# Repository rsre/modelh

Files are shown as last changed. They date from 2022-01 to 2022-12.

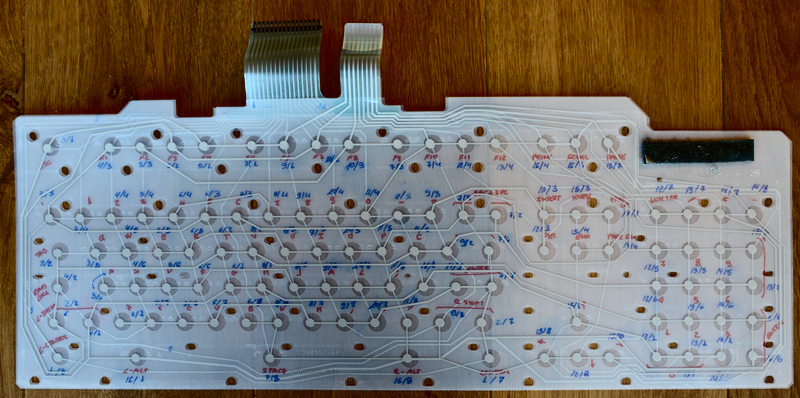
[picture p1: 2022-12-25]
firm/matrix/DSC_9299.jpg

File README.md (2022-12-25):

# Model H
Replacement Model M controller board



Still a work in progress.

## Part list

### 16 + 8 + 4 Pin Ribbons
* CONN FFC VERT 16POS 2.54MM PCB - https://www.digikey.com/products/en?keywords=A144434-ND
* CONN FFC VERT 8POS 2.54MM PCB - https://www.digikey.com/products/en?keywords=5-520315-8-ND
* CONN FFC VERT 4POS 2.54MM PCB - https://www.digikey.com/products/en?keywords=A123169-ND

### 16 + 12 Pin Ribbons
* CONN FFC VERT 16POS 2.54MM PCB - https://www.digikey.com/products/en?keywords=A144434-ND
* CONN FFC VERT 12POS 2.54MM PCB - https://www.digikey.com/products/en?keywords=A123179-ND

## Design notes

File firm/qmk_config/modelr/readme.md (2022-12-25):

# modelr

modelr

*A short description of the keyboard/project*

* Keyboard Maintainer: [Ricardo](https://github.com/rsre)
* Hardware Supported: *The PCBs, controllers supported*
* Hardware Availability: *Links to where you can find this hardware*

Make example for this keyboard (after setting up your build environment):

    make modelr:default

Flashing example for this keyboard:

    make modelr:default:flash

See the [build environment setup](https://docs.qmk.fm/#/getting_started_build_tools) and the [make instructions](https://docs.qmk.fm/#/getting_started_make_guide) for more information. Brand new to QMK? Start with our [Complete Newbs Guide](https://docs.qmk.fm/#/newbs).

## Bootloader

Enter the bootloader in 3 ways:

* **Bootmagic reset**: Hold down the key at (0,0) in the matrix (usually the top left key or Escape) and plug in the keyboard
* **Physical reset button**: Briefly press the button on the back of the PCB - some may have pads you must short instead
* **Keycode in layout**: Press the key mapped to `RESET` if it is available

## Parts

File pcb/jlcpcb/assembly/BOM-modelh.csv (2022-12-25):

Comment | Designator | Footprint | LCSC
1M | R11 | R_0603_1608Metric | C26098
8MHz | Y1 | Crystal_SMD_5032-2Pin_5.0x3.2mm | C115962
100nF | C10,C11,C12,C13,C14,C2,C4,C9 | C_0402_1005Metric | C1525
20pF | C5,C6 | C_0603_1608Metric | C1653
TYPE-C-31-M-12 | USB_C1 | USB_C_Receptacle_HRO_TYPE-C-31-M-12 | C165948
100 | R7,R8,R9 | R_0805_2012Metric | C17408
0 | R12,R13,R14,R15 | R_0805_2012Metric_Pad1.15x1.40mm_HandSolder | C17477
10uF | C1,C3 | C_0603_1608Metric | C19702
1.5k | R10,R16,R5 | R_0603_1608Metric | C22843
1M | R6 | R_0603_1608Metric | C22935
green | LED1,LED2 | LED_0805_2012Metric | C2297
330 | R1,R2 | R_0603_1608Metric | C23138
22 | R3,R4 | R_0603_1608Metric | C23345
100k | R17,R18 | R_0603_1608Metric | C25803
SW_Push | SW1 | SW_SPST_EVPBF | C318888
AMS1117-3.3 | U2 | SOT-223-3_TabPin2 | C6186
GD32F103C8T6 | U1 | LQFP-48_7x7mm_P0.5mm | C77994
Conn_02x05_Odd_Even | Debug1 | IDC-Header_2x05_P2.54mm_Vertical
Conn_02x03_Odd_Even | boot_selector1 | PinHeader_2x03_P2.54mm_Vertical
Conn_01x05 | custom_leds_C1 | PinSocket_1x05_P2.54mm_Vertical
Conn_01x05 | custom_leds_B1 | PinSocket_1x05_P2.54mm_Vertical
Conn_01x05 | custom_leds_A1 | PinSocket_1x05_P2.54mm_Vertical
TestPoint | TP1 | TestPoint_THTPad_D1.5mm_Drill0.7mm
5-520315-4 | LEDs1 | CONN_5-520315-4_TYC
6-520315-2 | Rows1 | CONN_6-520315-2_TYC
6-520315-6 | Columns1 | CONN_6-520315-6_TYC

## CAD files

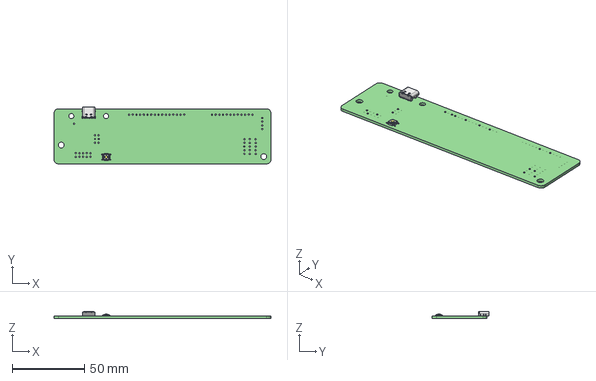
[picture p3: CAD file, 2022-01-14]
pcb/modelh.step
150.0 x 39.2 x 4.81 mm
modelh PCB

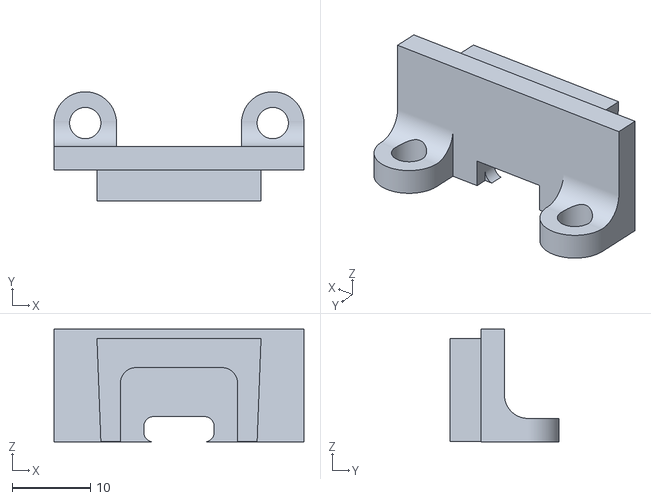
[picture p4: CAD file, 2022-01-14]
shim/shim.stl
32.0 x 14.0 x 14.4

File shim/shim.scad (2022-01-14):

$fn = 128;

total_height = 13.2;
ridge_height = 1.2;
pcb_height = 1.6;

usb_b_port_width = 12.5;
usb_b_port_height = 11.6;

module usb_b_port() {
	translate([-(usb_b_port_width / 2), -5,0])
		cube([usb_b_port_width, 18, usb_b_port_height]);
}

usb_c_port_width = 9;
usb_c_port_height = 3.25;
usb_c_port_radius = 1.25;
module usb_c_port() {
    r = usb_c_port_radius;
    w = usb_c_port_width;
    h = usb_c_port_height;
    
    translate([0,10,pcb_height])hull(){
        translate([-(w/2)+r, 0, -(h/2)+r])
            rotate([90,0,0])cylinder(h=18, r=r);
        translate([(w/2)-r, 0, -(h/2)+r])
            rotate([90,0,0])cylinder(h=18, r=r);
        translate([-(w/2)+r, 0, (h/2)-r])
            rotate([90,0,0])cylinder(h=18, r=r);
        translate([(w/2)-usb_c_port_radius, 0, (h/2)-r])
            rotate([90,0,0])cylinder(h=18, r=r);
    }
    
    translate([-(usb_c_port_width / 2), 1.5,0])
		cube([usb_c_port_width, 10, usb_c_port_height]);
    
    
    indentation_width = 15;
    indentation_height = 7.5;
    indentation_depth = 3.81;
    indentation_radius = 2;
    
    translate([-indentation_width/2, -4.01, 0])hull(){
        translate([indentation_width-indentation_radius, indentation_depth, indentation_height])
            rotate([90,0,0])cylinder(h=indentation_depth, r=indentation_radius);
        translate([+indentation_radius, indentation_depth, indentation_height])
            rotate([90,0,0])cylinder(h=indentation_depth, r=indentation_radius);
		cube([indentation_width, indentation_depth, indentation_height-indentation_radius]);
    }
}

module pegs() {
	translate([-12,6,0])
		cylinder(10, 2, 2);
	translate([12,6,0])
		cylinder(10, 2, 2);
}

module outer() {
    port_height = total_height;
    port_width_small = 20;
    port_width_big = 21;
    port_thickness = 4;
	
    translate([0, 0, 0.01])
        difference(){
            linear_extrude(height = port_height, scale = port_width_big/port_width_small) square(port_width_small, center = true);
            translate([-25/2,-20-port_thickness,-1])cube([25, 20, port_height+2]);
            translate([-25/2,3,-1])cube([25, 20, port_height+2]);
        }
}

module inner() {
	translate([-16, 0, 0.01])
		cube([32, 3, total_height + ridge_height]);
}

module base() {
	difference() {
		union() {
			translate([-16, 0, 0.01])
				cube([32, 6, 3]);
			translate([-12,6,0.01])
				cylinder(3, 4, 4);
			translate([12,6,0.01])
				cylinder(3, 4, 4);

			translate([-16, 0, 3])
				cube([32, 6, 3]);
		}
		union() {
			translate([-8,-5,0])
				cube([16, 18, 11]);

			translate([-16.1,6,6]) {
				rotate([0,90,0]) {
					cylinder(33, 3, 3);
				}
			}
		}
	}
}


module fill() {
	outer();
	inner();
	base();
}

//translate([88.78,-46,-pcb_height])rotate([0,0,180])color("blue")import("../pcb/modelh.stl");

difference() {
	fill();
	usb_c_port();
	pegs();
}

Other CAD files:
pcb/modelh.stl

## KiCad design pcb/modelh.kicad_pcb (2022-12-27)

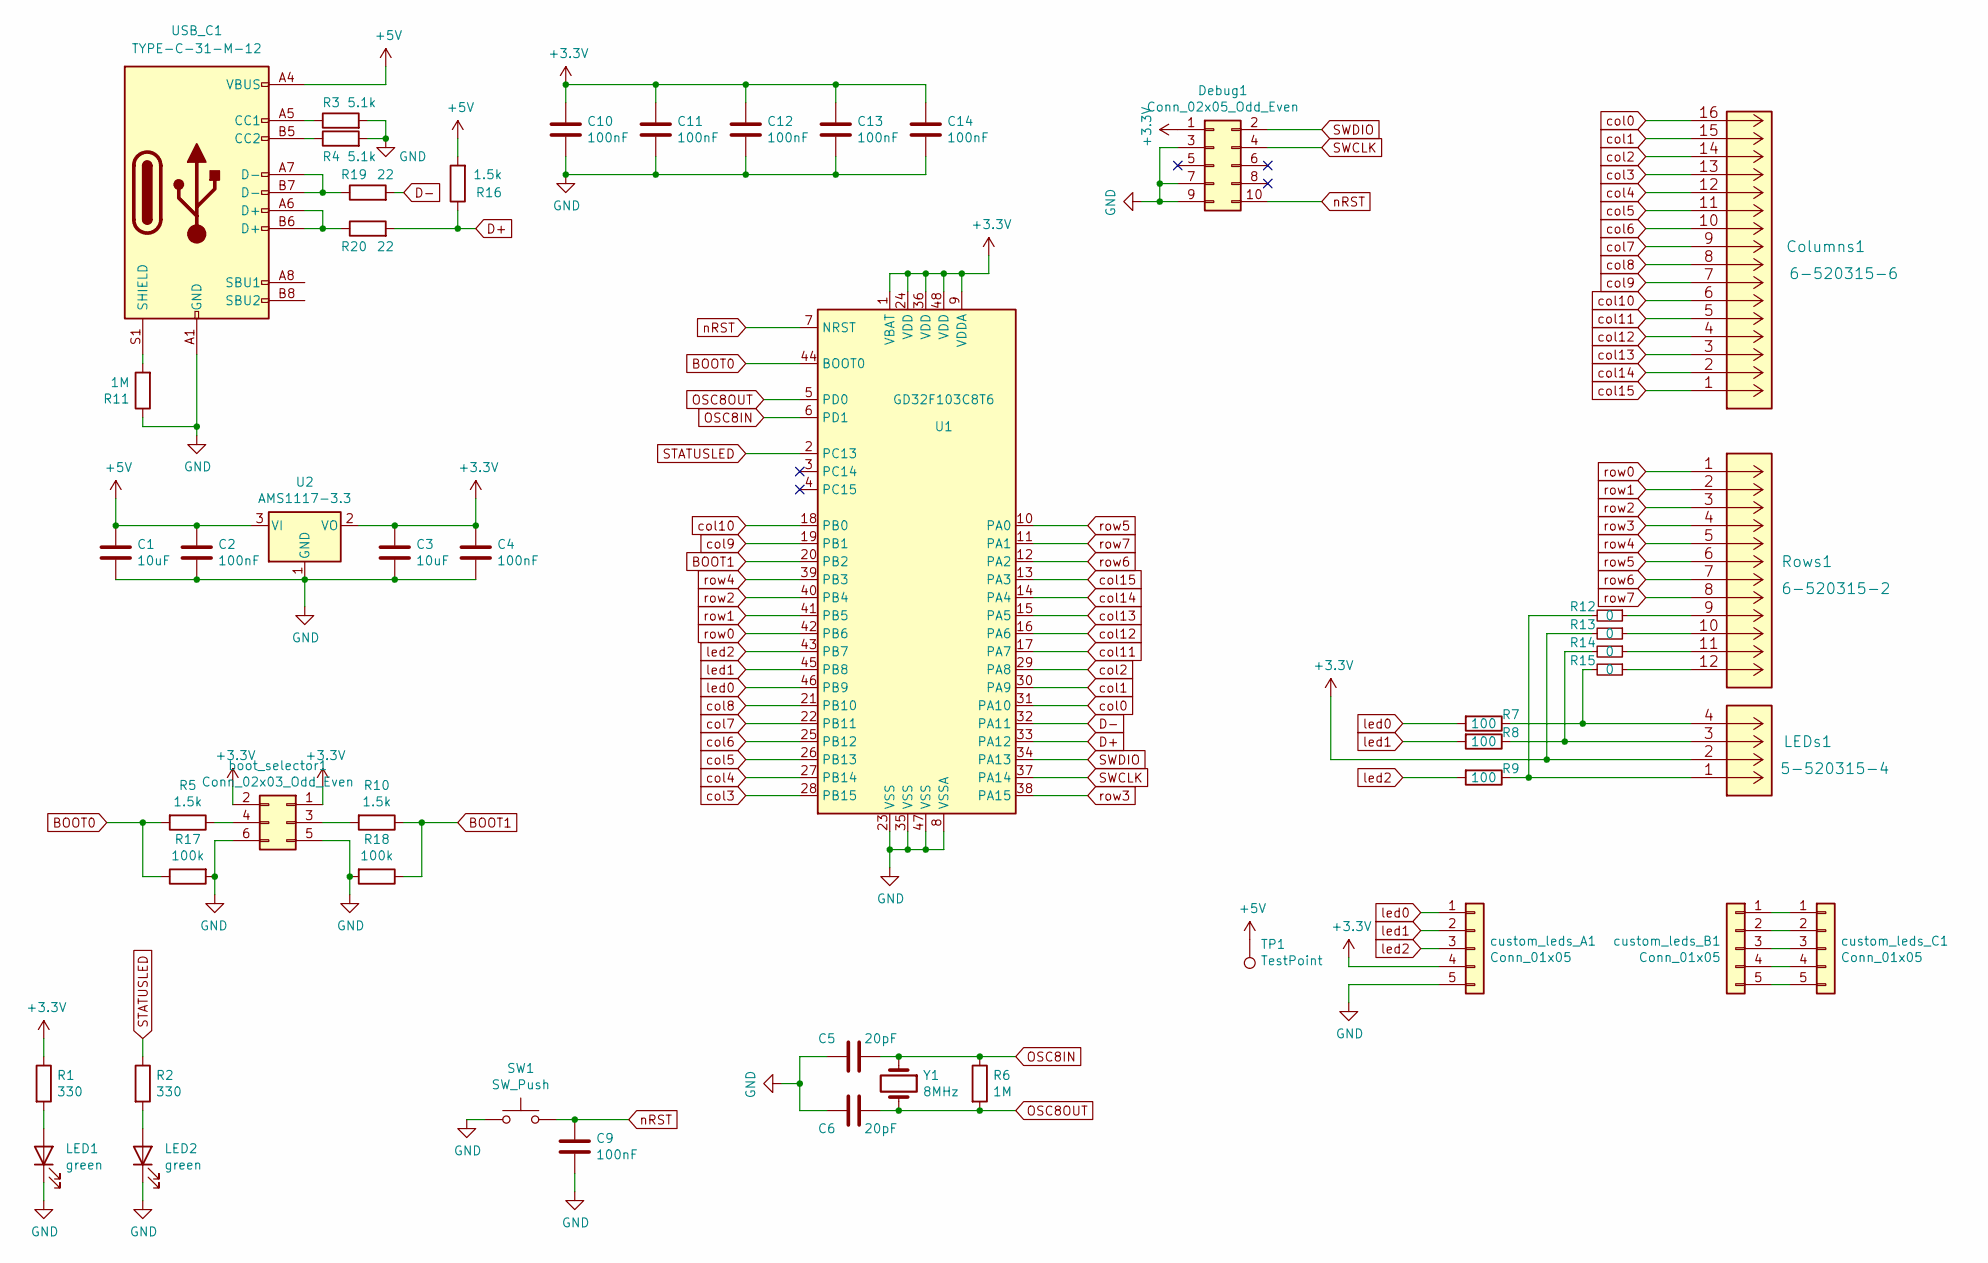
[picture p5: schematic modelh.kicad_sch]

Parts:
C1, C3: 10uF; C_0603_1608Metric; LCSC C19702
C2, C4, C9, C10, C11, C12, C13, C14: 100nF; C_0402_1005Metric; LCSC C1525
C5, C6: 20pF; C_0603_1608Metric; LCSC C1653
Columns1: 6-520315-6; CONN_6-520315-6_TYC
Debug1: Conn_02x05_Odd_Even; IDC-Header_2x05_P2.54mm_Vertical
LED1, LED2: green; LED_0805_2012Metric; LCSC C2297
LEDs1: 5-520315-4; CONN_5-520315-4_TYC
R1, R2: 330; R_0603_1608Metric; LCSC C23138
R3, R4: 5.1k; R_0603_1608Metric; LCSC C23345
R5, R10, R16: 1.5k; R_0603_1608Metric; LCSC C22843
R6: 1M; R_0603_1608Metric; LCSC C22935
R7, R8, R9: 100; R_0805_2012Metric; LCSC C17408
R11: 1M; R_0603_1608Metric; LCSC C26098
R12, R13, R14, R15: 0; R_0805_2012Metric_Pad1.15x1.40mm_HandSolder; LCSC C17477
R17, R18: 100k; R_0603_1608Metric; LCSC C25803
R19, R20: 22; R_0603_1608Metric; LCSC C23345
Rows1: 6-520315-2; CONN_6-520315-2_TYC
SW1: SW_Push; SW_SPST_EVPBF; LCSC C318888
TP1: TestPoint; TestPoint_THTPad_D1.5mm_Drill0.7mm
U1: GD32F103C8T6; LQFP-48_7x7mm_P0.5mm; LCSC C77994
U2: AMS1117-3.3; SOT-223-3_TabPin2; LCSC C6186
USB_C1: TYPE-C-31-M-12; USB_C_Receptacle_HRO_TYPE-C-31-M-12; LCSC C165948
Y1: 8MHz; Crystal_SMD_5032-2Pin_5.0x3.2mm; LCSC C115962
boot_selector1: Conn_02x03_Odd_Even; PinHeader_2x03_P2.54mm_Vertical
custom_leds_A1: Conn_01x05; PinSocket_1x05_P2.54mm_Vertical
custom_leds_B1: Conn_01x05; PinSocket_1x05_P2.54mm_Vertical
custom_leds_C1: Conn_01x05; PinSocket_1x05_P2.54mm_Vertical

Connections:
+3V3: C3.1, C4.1, C10.1, C11.1, C12.1, C13.1, C14.1, Debug1.1, LEDs1.2, R1.1, R13.2, U1.1 (VBAT), U1.9 (VDDA), U1.24 (VDD), U1.36 (VDD), U1.48 (VDD), U2.2 (VO), boot_selector1.1, boot_selector1.2, custom_leds_A1.4
+5V: C1.1, C2.1, R16.2, TP1.1, U2.3 (VI), USB_C1.A4 (VBUS), USB_C1.A9 (VBUS), USB_C1.B4 (VBUS), USB_C1.B9 (VBUS)
BOOT0: R5.2, R17.1, U1.44 (BOOT0)
BOOT1: R10.1, R18.1, U1.20 (PB2)
D-: R19.2, U1.32 (PA11)
GND: C1.2, C2.2, C3.2, C4.2, C5.2, C6.2, C9.2, C10.2, C11.2, C12.2, C13.2, C14.2, Debug1.3, Debug1.7, Debug1.9, LED1.1 (K), LED2.1 (K), R3.2, R4.2, R11.1, R17.2, R18.2, SW1.1, U1.8 (VSSA), U1.23 (VSS), U1.35 (VSS), U1.47 (VSS), U2.1 (GND), USB_C1.A1 (GND), USB_C1.A12 (GND), USB_C1.B1 (GND), USB_C1.B12 (GND), boot_selector1.5, boot_selector1.6, custom_leds_A1.5
unnamed: LED1.2 (A), R1.2
unnamed: LED2.2 (A), R2.2
unnamed: LEDs1.1, R9.1, R12.2
unnamed: LEDs1.3, R8.1, R14.2
unnamed: LEDs1.4, R7.1, R15.2
unnamed: R3.1, USB_C1.A5 (CC1)
unnamed: R4.1, USB_C1.B5 (CC2)
unnamed: R5.1, boot_selector1.4
unnamed: R10.2, boot_selector1.3
unnamed: R11.2, USB_C1.S1 (SHIELD)
unnamed: R12.1, Rows1.9
unnamed: R13.1, Rows1.10
unnamed: R14.1, Rows1.11
unnamed: R15.1, Rows1.12
unnamed: R19.1, USB_C1.A7 (D-), USB_C1.B7 (D-)
unnamed: custom_leds_B1.1, custom_leds_C1.1
unnamed: custom_leds_B1.2, custom_leds_C1.2
unnamed: custom_leds_B1.3, custom_leds_C1.3
unnamed: custom_leds_B1.4, custom_leds_C1.4
unnamed: custom_leds_B1.5, custom_leds_C1.5
OSC8IN: C5.1, R6.1, U1.6 (PD1), Y1.1
OSC8OUT: C6.1, R6.2, U1.5 (PD0), Y1.2
STATUSLED: R2.1, U1.2 (PC13)
SWCLK: Debug1.4, U1.37 (PA14)
SWDIO: Debug1.2, U1.34 (PA13)
col0: Columns1.16, U1.31 (PA10)
col1: Columns1.15, U1.30 (PA9)
col2: Columns1.14, U1.29 (PA8)
col3: Columns1.13, U1.28 (PB15)
col4: Columns1.12, U1.27 (PB14)
col5: Columns1.11, U1.26 (PB13)
col6: Columns1.10, U1.25 (PB12)
col7: Columns1.9, U1.22 (PB11)
col8: Columns1.8, U1.21 (PB10)
col9: Columns1.7, U1.19 (PB1)
col10: Columns1.6, U1.18 (PB0)
col11: Columns1.5, U1.17 (PA7)
col12: Columns1.4, U1.16 (PA6)
col13: Columns1.3, U1.15 (PA5)
col14: Columns1.2, U1.14 (PA4)
col15: Columns1.1, U1.13 (PA3)
led0: R7.2, U1.46 (PB9), custom_leds_A1.1
led1: R8.2, U1.45 (PB8), custom_leds_A1.2
led2: R9.2, U1.43 (PB7), custom_leds_A1.3
nRST: C9.1, Debug1.10, SW1.2, U1.7 (NRST)
row0: Rows1.1, U1.42 (PB6)
row1: Rows1.2, U1.41 (PB5)
row2: Rows1.3, U1.40 (PB4)
row3: Rows1.4, U1.38 (PA15)
row4: Rows1.5, U1.39 (PB3)
row5: Rows1.6, U1.10 (PA0)
row6: Rows1.7, U1.12 (PA2)
row7: Rows1.8, U1.11 (PA1)

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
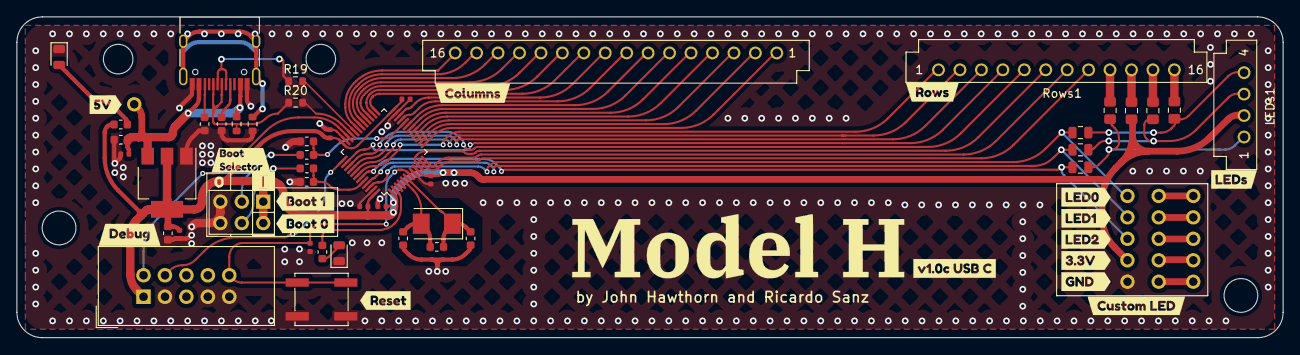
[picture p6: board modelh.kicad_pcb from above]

Board: 2 copper layers, 150.0 x 38.0 mm, 70 parts (0 on the bottom side), 61 nets.

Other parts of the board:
HOLE1, HOLE2: MountingHole_3.5mm
HOLE3, HOLE4: MountingHole_4mm
MODELH_LOGO: LOGO; modelh_logo
kibuzzard-61E6F38C: G***; kibuzzard-61E6F38C
kibuzzard-61E6F754: G***; kibuzzard-61E6F754
kibuzzard-61E18CD3: G***; kibuzzard-61E18CD3
kibuzzard-61E18CE3: G***; kibuzzard-61E18CE3
kibuzzard-61E67D4F: G***; kibuzzard-61E67D4F
kibuzzard-61E83ADE: G***; kibuzzard-61E83ADE
kibuzzard-61E84BB4: G***; kibuzzard-61E84BB4
kibuzzard-61E84BBD: G***; kibuzzard-61E84BBD
kibuzzard-61E846DB: G***; kibuzzard-61E846DB
kibuzzard-61E1917D: G***; kibuzzard-61E1917D
kibuzzard-61E1928B: G***; kibuzzard-61E1928B
kibuzzard-61E1934D: G***; kibuzzard-61E1934D
kibuzzard-61E1935A: G***; kibuzzard-61E1935A
kibuzzard-61E19345: G***; kibuzzard-61E19345
kibuzzard-61E19354: G***; kibuzzard-61E19354
kibuzzard-61E19361: G***; kibuzzard-61E19361
kibuzzard-61E19404: G***; kibuzzard-61E19404

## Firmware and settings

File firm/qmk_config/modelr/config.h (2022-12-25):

// Copyright 2022 Ricardo (@rsre)
// SPDX-License-Identifier: GPL-2.0-or-later

#pragma once

// Fix #error "TIM2 is not a 32bits timer"
// https://deskthority.net/viewtopic.php?p=265193&sid=2bc560dfc0e2d3b7254a652c62e042c6#p265193
#define CH_CFG_ST_RESOLUTION                16

#define LED_PIN_ON_STATE					0
#define LED_NUM_LOCK_PIN					B7
#define LED_CAPS_LOCK_PIN					B8
#define LED_SCROLL_LOCK_PIN					B9
/*
 * Feature disable options
 *  These options are also useful to firmware size reduction.
 */

/* disable debug print */
//#define NO_DEBUG

/* disable print */
//#define NO_PRINT

/* disable action features */
//#define NO_ACTION_LAYER
//#define NO_ACTION_TAPPING
//#define NO_ACTION_ONESHOT

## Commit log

2022-01-14 Substitutes USB B connector with USB C connector
    [modelh-B_Cu.gbr, modelh-B_Mask.gbr, modelh-B_Paste.gbr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]
2022-01-14 Updates 3D models and moves USB closer to edge
    [modelh-B_Cu.gbr, modelh-B_Mask.gbr, modelh-B_Paste.gbr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]
2022-01-14 Updates connector footprint
    [modelh.csv, modelh.kicad_pcb]
2022-01-14 Adds 3D files to repository
    [modelh.kicad_pcb, modelh.step]
2022-01-14 Updates shim for USB C
    [modelh.stl, shim.scad, shim.stl]
2022-01-17 Remove old gerbers
    [modelh-B_Cu.gbr, modelh-B_Mask.gbr, modelh-B_Paste.gbr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]
2022-01-17 Renames a few components
    [modelh.kicad_pcb, modelh.kicad_sch]
2022-01-17 Generate JLC PCB files
    [BOM-modelh.csv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]
2022-01-17 Removes JLC PCB production files
    [BOM-modelh.csv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]
2022-01-17 Updates some components
    [modelh.kicad_pcb, modelh.kicad_sch]
2022-01-19 Updates TE connectors footprints
    [modelh.kicad_pcb, modelh.kicad_sch]
2022-01-19 Updates silkscreen to make clear boot selector
    [modelh.kicad_pcb, modelh.kicad_sch]
2022-01-19 Adjust footprints
    [modelh.kicad_pcb]
2022-01-19 JLC PCB Production files
    [BOM-modelh.csv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]
2022-02-09 Adds hatched pattern to groundplane
    [modelh.kicad_pcb]
2022-02-09 Places USB C connector completely inside the board
    [modelh.kicad_pcb]
2022-02-26 Adds missing 1.5k pullup resistor to USB D+ line
    [modelh.kicad_pcb, modelh.kicad_sch]
2022-12-25 Add gerbers
    [BOM-modelh.csv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]
2022-12-25 Update schematics and pcb
    [modelh.kicad_pcb, modelh.kicad_sch]
2022-12-25 Update gitignore to be the standard kicad one
2022-12-25 Update README to reflect all different connector requirements
2022-12-27 Add proper CC resistors for USB C
    [modelh.kicad_pcb, modelh.kicad_sch]
2022-12-27 Move pull up in front of 0 ohm resistors
    [modelh.kicad_sch]
